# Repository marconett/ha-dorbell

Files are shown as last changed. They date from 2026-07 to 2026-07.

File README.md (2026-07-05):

# ha-doorbell

Makes a classic german wired doorbell ([Grothe Gong 165](https://www.urmet.de/media/7e/de/96/1769671346/Installationsanleitung_Elektromechanische-Gongs_165-Reihe.pdf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)) show up in Home Assistant as `binary_sensor.doorbell`, without touching the mains wiring or running new cables.

No dedicated power source is needed, the sender runs off the same voltage that powers the bell.

The link between bell and Home Assistant is a 433 MHz radio signal.

## How it fits together

```
Doorbell button -> Bell transformer -> gong terminals ─> [sender] ~~~ 433 MHz ~~~ [receiver] -> Wi-Fi -> Home Assistant
```

- **[sender/](sender)**: A small board wired to the gong terminals. It is powered by the bell voltage itself: pressing the button powers a TX118SA-4 module that transmits while the button is held. No battery, no extra supply.
- **[receiver/](receiver)**: An always-on, USB-powered ESP32-C6 with an RX480E-4 receiver, running ESPHome. It exposes the doorbell as a binary sensor that Home Assistant auto-discovers.

A note on antennas: While my documentation referes to 17.3 cm straight wire antennas throughout, the [433 kit](https://www.amazon.de/QIACHIP-Fernbedienung-integrierter-4-Kanal-Ausgang-Empfänger-Set/dp/B06ZZ1Z6R7) I bought included two small, coiled antennas and I ended up using those.

## Getting started

1. Measure your bell's terminal voltage to confirm the design fits: [bell_measurement.md](bell_measurement.md)
2. Build and install the sender: [sender/README.md](sender/README.md)
3. Build, flash, and pair the receiver: [receiver/README.md](receiver/README.md)
4. You now have a binary sensor in Home Assistant that changes state while the doorbell button is pressed

## WARNING

> **No guarantees.** I am not an electrician; these instructions document what worked for *my* bell (Grothe Gong 165, 8–12 V AC at the gong terminals) and come without any warranty. Similar setups will likely work the same way, but wiring schemes differ. Your bell circuit may carry higher voltage or current and may be dangerous. When in doubt have the work done or checked by a qualified electrician. Proceed at your own risk.

## Images

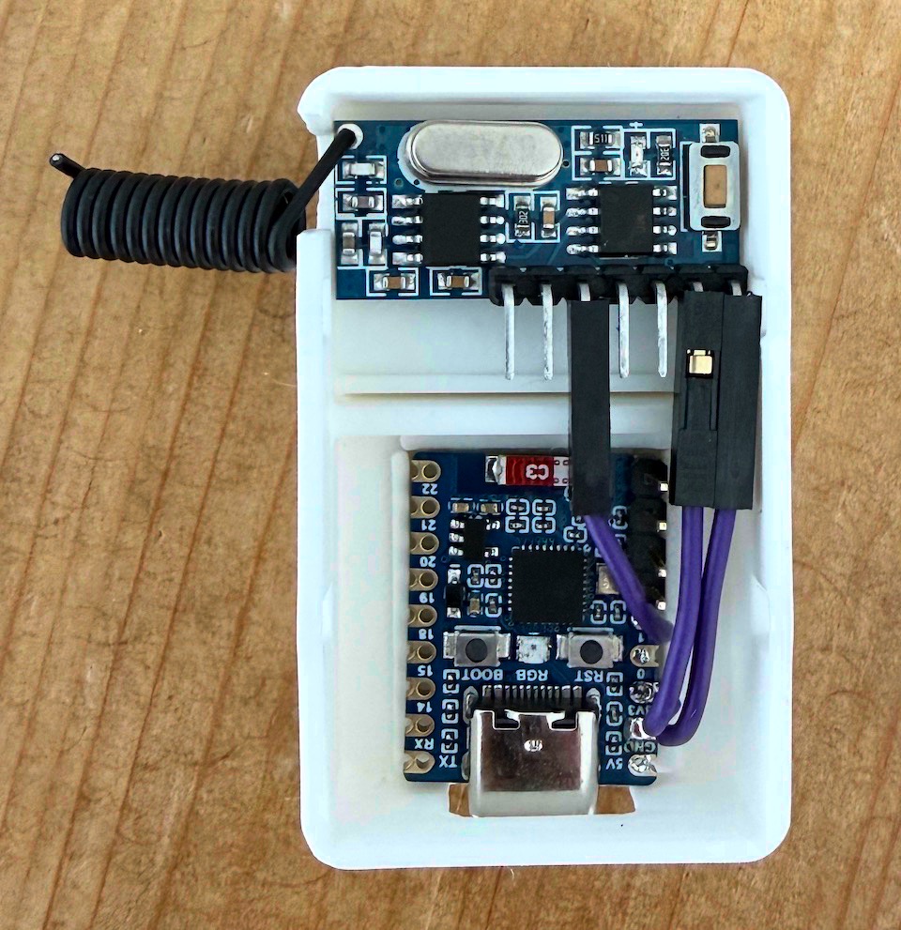
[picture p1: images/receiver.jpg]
Receiver
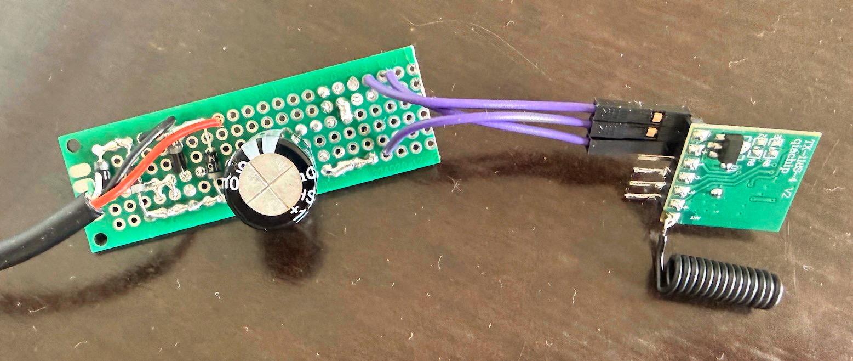
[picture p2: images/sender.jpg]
Sender


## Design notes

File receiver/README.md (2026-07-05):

# 433 MHz Doorbell Receiver

Always-on, USB-powered receiver that turns a press of the 433 MHz doorbell sender (see `../sender`) into a `binary_sensor.doorbell` entity in Home Assistant.

## Parts

- **Waveshare ESP32-C6-Zero** (any ESP32-C6 devkit works)
- **RX480E-4**: 433 MHz receiver with built-in learning decoder
- 17.3 cm straight wire as antenna, soldered to the module's ANT pad
- Data-capable USB-C cable + USB power supply

## Wiring

| ESP32-C6 | RX480E-4 |
|---|---|
| 3V3 | VCC |
| GND | GND |
| GPIO1 | **D2** |

D0/D1/D3 stay unconnected. No other components needed.

> The learned code may land on a different D pin than D2 on other units: after pairing, check which output goes HIGH while the sender transmits and wire GPIO1 to that one.

## Pair the RX480E-4 to the sender (one-time)

Done entirely on the module, nothing to flash for this step:

1. Power the module.
2. Tap the on-board **learn button once** (LED lights), this selects momentary mode.
3. Press the doorbell. The LED blinks and turns off. Sender and receiver are now paired.
4. Press the doorbell again: the module LED should light for the duration of the press.

The pairing is stored in the module and survives power loss. To erase, hold the learn button ~8 s until the LED flashes.

## Flash the firmware

1. Install ESPHome
2. Create `secrets.yaml` next to `doorbell-receiver.yaml`:

   ```yaml
   wifi_ssid: "YourNetworkName"
   wifi_password: "YourWifiPassword"
   ```

3. Plug the board in via USB and run:

   ```sh
   esphome run receiver/doorbell-receiver.yaml
   ```

   Pick the correct serial port when asked. If no port shows up: swap in a data-capable cable, or enter download mode manually (hold **BOOT**, tap **RESET**, release BOOT, retry).

4. The command attaches to the log stream after flashing. Press the doorbell. The log should show the `Doorbell` sensor turning **ON**, then **OFF** ~1.5 s after release. Later updates work over Wi-Fi (OTA), no USB needed.

Alternatively, use ESPHome Device Builder to setup and flash the device.

## Connect to Home Assistant

Home Assistant auto-discovers the device: **Settings -> Devices & Services** -> the ESPHome card shows *doorbell-receiver* -> **Configure**. Trigger automations on `binary_sensor.doorbell` turning on.

## Enclosure

I provided a 3d printable enclosure in the form of .stl files.

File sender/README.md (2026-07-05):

# 433 MHz Doorbell Sender

Powered directly from the bell wires: when the doorbell button is pressed, ~8 V AC appears on the gong terminals, gets rectified, and powers a TX118SA-4 transmitter whose channel K1 is permanently tied to GND, so power-up = transmitting. No battery, no permanent supply.

Before building, measure your own bell as described in [../bell_measurement.md](../bell_measurement.md). This design assumes the ideal case: 0 V idle, constant 8–12 V AC while the button is held.

## Parts

| Ref | Part |
|---|---|
| D1–D4 | 4× Schottky diode **1N5819** (bridge rectifier) |
| C1 | Electrolytic capacitor **1000 µF / 35 V** |
| TX1 | **TX118SA-4** 433 MHz transmitter (3–24 V variant. Check before wiring, a 3.3–5 V variant needs a 5 V regulator) |
| ANT | 17.3 cm straight wire, soldered to the module's ANT pad |
| - | Perfboard, 2-pin screw terminal, wire, small enclosure |

Build in three stages, each verified before the next.

## Stage 1: Breadboard quick test (module only)

Confirms the module transmits continuously while powered with K1 grounded.

| TX118SA-4 pad | Connect to |
|---|---|
| VCC | +5 V supply |
| GND | supply GND |
| K1 (channel A) | short to GND |
| ANT | 17.3 cm wire, kept straight |

Pair the receiver as described in [../receiver/README.md](../receiver/README.md). The module should transmit and the receiver triggers for as long as power is applied.

## Stage 2: Breadboard final circuit

The full circuit (bridge -> C1 -> module), still on the 5 V bench supply.

Breadboard setup

Orientation: diode band (silver/gray stripe) = cathode; C1's longer leg = **+**, stripe = **−**. Use the breadboard rails as **V+** and **GND**; pick two free columns as bridge inputs **AC1** and **AC2** (the supply leads plug in there. On the final board this is where the gong wires land).

| Part | From | To |
|---|---|---|
| D1 | anode: AC1 | cathode (band): V+ rail |
| D2 | anode: AC2 | cathode (band): V+ rail |
| D3 | anode: GND rail | cathode (band): AC1 |
| D4 | anode: GND rail | cathode (band): AC2 |
| C1 | **+**: V+ rail | **−** (stripe): GND rail |
| TX118SA-4 | VCC: V+ rail, GND + K1: GND rail | ANT: 17.3 cm wire |

Quick check: all four diode bands "point away" from GND. A flipped diode or reversed C1 shorts the bridge.

Tests, in order:

1. **Pre-power**: no supply: resistance/diode mode between V+ and GND must not read a short (a slowly climbing value while C1 charges is normal).
2. **DC smoke test**: 5 V into AC1, 0 V into AC2 (into the AC columns, *not* the rails): expect **V+ ≈ 4.2–4.5 V** and the receiver triggers.
3. **Polarity swap**: swap the supply leads: must work identically (AC has no polarity).

## Stage 3: Perfboard and install

Solder the identical circuit onto a perfboard (also see `perfboard.diy` for a [DIYLC](https://bancika.github.io/diy-layout-creator/) file).

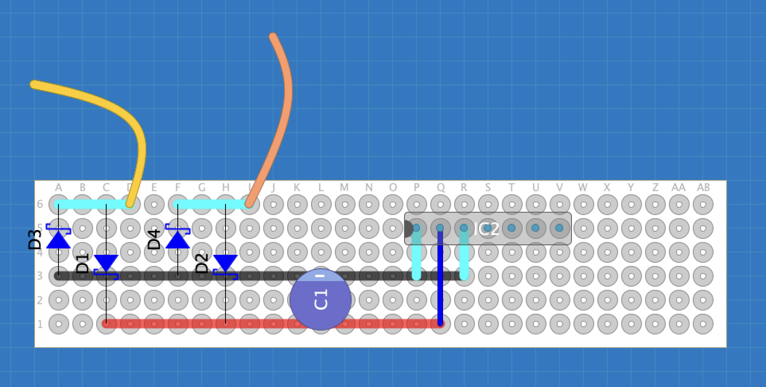
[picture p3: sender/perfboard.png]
Perfboard layout


Component side:

| Part | Holes | Orientation |
|---|---|---|
| J1 wires (to the gong) | `D6` (AC1), `I6` (AC2) | off-board hookup wires (yellow/orange in the image) |
| D1 | anode `C6` -> cathode `C1` | along column C, band toward row 1 |
| D2 | anode `H6` -> cathode `H1` | along column H, band toward row 1 |
| D3 | anode `A3` -> cathode `A6` | along column A, band toward row 6 |
| D4 | anode `F3` -> cathode `F6` | along column F, band toward row 6 |
| C1 | `L1` (+), `L3` (− stripe) | 5 mm pitch fits the 2-row spacing |
| TX118SA-4 | header into `P5`–`V5` | upright along the top edge; GND lands in `P5`, V+ in `Q5`, K1 in `R5` |
| V+ jumper | `Q1` -> `Q5` | insulated wire (dark blue): it crosses the GND run at `Q3` and must not touch it |
| Antenna | - | soldered to the module's ANT pad, pointing up |

Solder side (bare bus wire flat along the rows):

| Net | Run | Joins |
|---|---|---|
| AC1 | row 6, `A6`–`D6` | J1 wire, D3 cathode, D1 anode |
| AC2 | row 6, `F6`–`I6` | J1 wire, D4 cathode, D2 anode |
| V+ | row 1, `C1`–`Q1` | D1 cathode, D2 cathode, C1 +, V+ jumper up to the module |
| GND | row 3, `A3`–`R3`, plus risers `P3`–`P5` and `R3`–`R5` | D3 anode, D4 anode, C1 −, module GND, K1 |

**Install:** connect J1 across the gong's terminals (either way round - the bridge handles both polarities). Mount the board in a small enclosure near the gong, antenna straight and unobstructed.

## Enclosure

No enclosure is provided. The goal was to fit the board into the enclosure of the bell itself, but because the capacitor ended up being very large and because the whole thing was rather unwieldy, i ended up cutting a small hole into the bells enclosure and haveing the raw board hanging outside the bell.

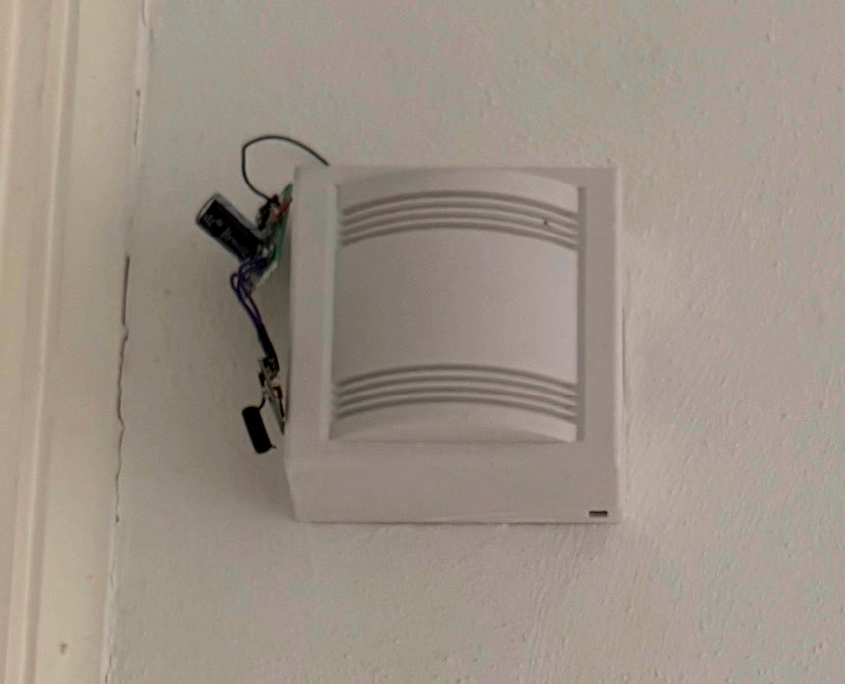
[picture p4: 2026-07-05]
images/final.jpg

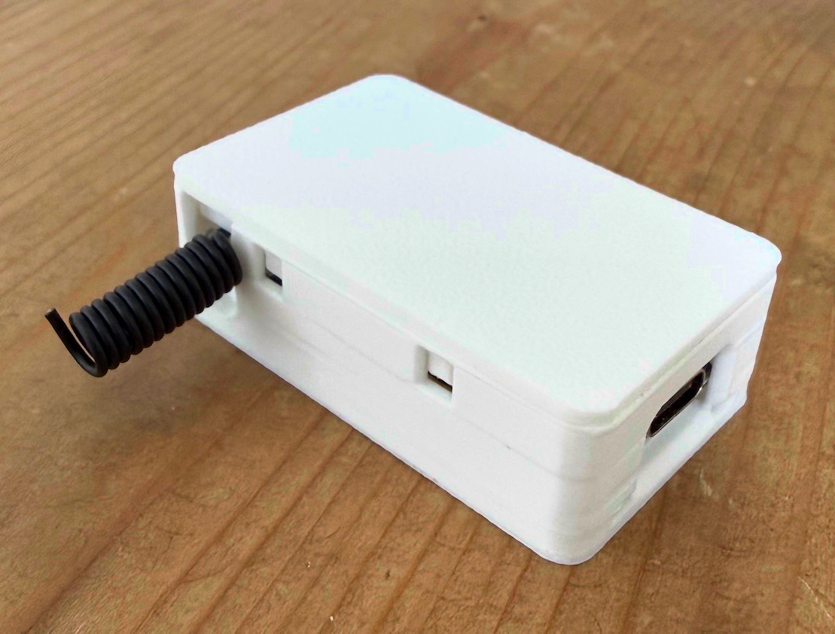
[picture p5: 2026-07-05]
images/enclosure.jpg

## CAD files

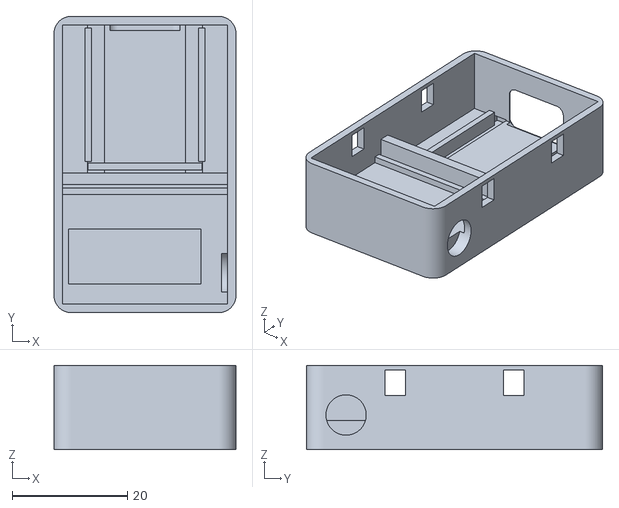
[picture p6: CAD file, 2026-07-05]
receiver/enclosure/case.stl
31.6 x 51.5 x 14.6

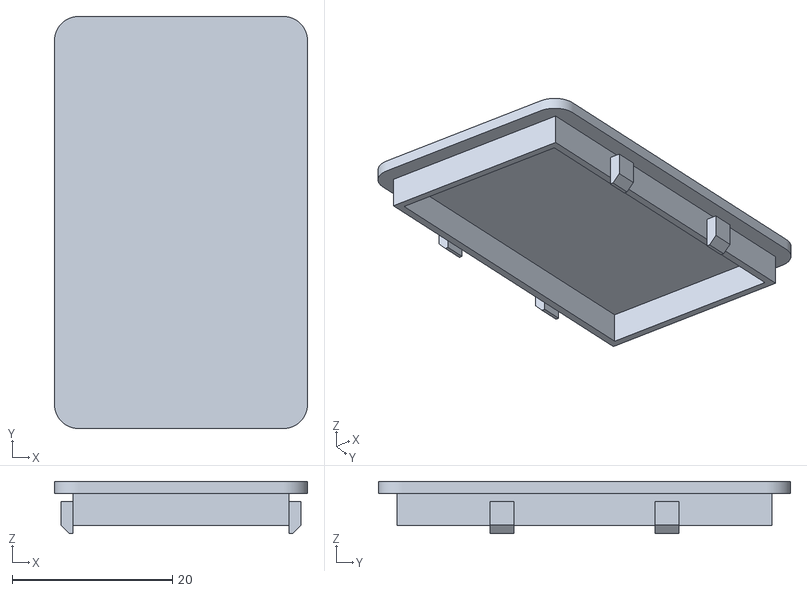
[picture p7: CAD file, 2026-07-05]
receiver/enclosure/lid.stl
31.6 x 51.5 x 6.50

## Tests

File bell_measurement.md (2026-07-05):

# Measuring the Bell Voltage

One multimeter measurement at the gong terminals (**0/3** for my Grothe Gong 165) answers the two questions the sender design depends on: (1) is there voltage only while the button is pressed, and (2) does it stay constant for the whole press?

## Safety

- Measure **only** at gong terminals 0 and 3 (8–12 V AC).
- **Never** measure on the mains/230 V side of the bell transformer.
- The system must be powered on.

## Multimeter setup

1. Mode: **AC voltage** (V~ / ACV, not DC).
2. Range: 20 V~ or autorange.
3. Leads: black in **COM**, red in **VΩ** (not the current/"A" jack).
4. Enable **min/max** if available, it catches short spikes.

## Procedure

1. **Idle:** probes on terminals 0 and 3 (polarity irrelevant), nobody ringing. Note the value.
2. **Press and hold** the doorbell button (easiest with two people). Keep the probes in place.
3. **Watch the display for 3–5 s** while holding, the meter needs ~1 s to settle. Note how high the value goes and whether it holds steady or drops.
4. Cross-check with a few short presses and one long press.

## Interpreting the result

**Question 1: idle vs. pressed:**

- **Idle ≈ 0 V, pressed ≈ 8–12 V** -> ideal case, the sender design works as-is. ✅
- **Idle low (2–4 V), pressed clearly higher** -> standing voltage present; the module would need permanent power plus a threshold trigger (transistor + Zener). Design change required.
- **Idle ≈ pressed** -> the terminals reveal nothing about ringing; power/trigger from the bell wires is impossible. Use a battery-powered sensor that detects the gong physically instead.

**Question 2: while held:**

- **Value stays constant for the whole press** -> the module is powered (and transmits) continuously while ringing, as the design assumes. ✅
- **Only a brief spike, then back to ~0 V despite holding** -> only a short pulse; a larger buffer capacitor or different trigger logic would be needed.

## Notes

- Also check once in **DC mode**: a significant DC reading at idle points to a different wiring scheme. Investigate before building.
